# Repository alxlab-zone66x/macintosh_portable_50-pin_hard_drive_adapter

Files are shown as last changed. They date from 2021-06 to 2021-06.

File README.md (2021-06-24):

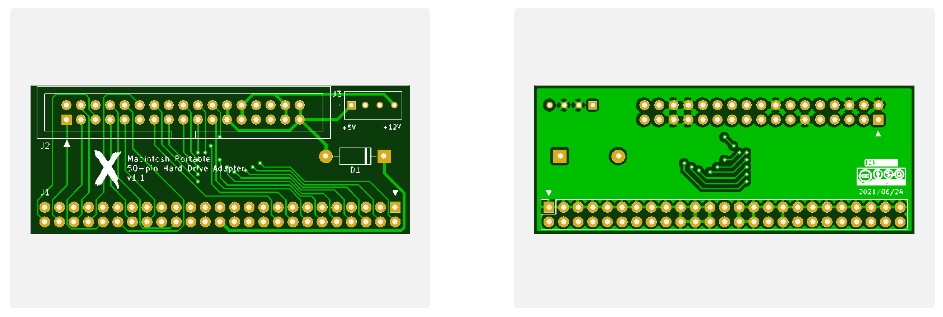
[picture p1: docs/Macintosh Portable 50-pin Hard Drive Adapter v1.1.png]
Macintosh Portable 50-pin Hard Drive Adapter v1.1


# Macintosh Portable 50-pin Hard Drive Adapter v1.1

An adapter to allow you to use any standard 50-pin SCSI device as the Macintosh Portable hard drive. In particular it would work well for connecting directly to the back of a 50-pin SCSI hard drive.

Discord Open Retro SCSI skunkworks

Join us in #skunkworks on [Discord](https://discord.gg/GKcvtgU7P9) to help make retro solutions available to all.

## Bill of Materials

| Quantity | Product Number | Datasheet |
| :--- | --- | --- |
| 1 | BHR-34-VUA | https://app.adam-tech.com/products/download/data_sheet/203218/bhr-xx-vua-data-sheet.pdf |
| 1 | SFH11-PBPC-D17-ST-BK | https://s3.amazonaws.com/catalogspreads-pdf/PAGE123%20.100%20SFH11%20SERIES%20FEMALE%20HDR%20ST%20RA.pdf |
| 1 | 171825-4 | https://media.digikey.com/pdf/Data%20Sheets/Tyco%20Electonics%20AMP%20PDFs/Post%20Headers%20(Board%20Applied).pdf |
| 1 | 1N5818-T | https://www.diodes.com/assets/Datasheets/ds23001.pdf |
| 1 | 34-pin ribbon cable 20cm | https://www.aliexpress.com/item/32985603139.html?spm=a2g0s.9042311.0.0.8a744c4dZvpend |
| 1 | power cable | https://www.aliexpress.com/item/1005002510893961.html?spm=a2g0s.9042311.0.0.38264c4dVYgWFl |

## License



This work is licensed under a <a rel="license" href="http://creativecommons.org/licenses/by-nc-sa/4.0/">Creative Commons Attribution-NonCommercial-ShareAlike 4.0 International License</a>.

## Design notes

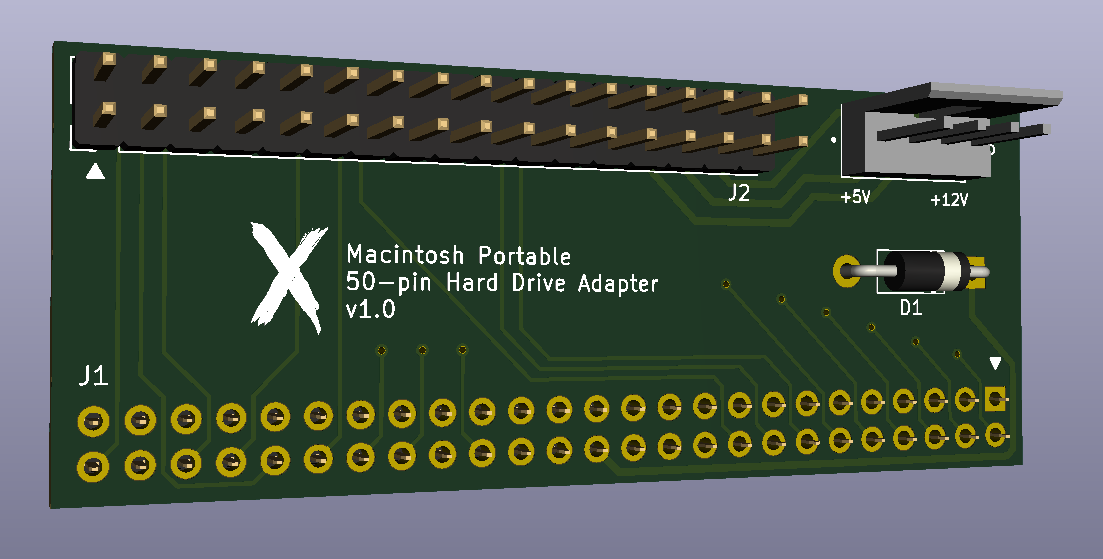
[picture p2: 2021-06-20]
docs/macintosh_portable_50-pin_hard_drive_adapter_v1.0.png

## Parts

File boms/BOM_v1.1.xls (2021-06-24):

Comment | Designator | LCSC Part #（optional） | Part # | Alternate Part # | Quantity | Datasheet
2 x 25-pin 2.54mm polarizing key female header | J1 |  | BHR-34-VUA |  | 1 | https://app.adam-tech.com/products/download/data_sheet/203218/bhr-xx-vua-data-sheet.pdf
2x17-pin 2.54mm shrouded polarizing key male header | J2 |  | SFH11-PBPC-D17-ST-BK | 6834-4500PL | 1 | https://s3.amazonaws.com/catalogspreads-pdf/PAGE123%20.100%20SFH11%20SERIES%20FEMALE%20HDR%20ST%20RA.pdf
4-pin power connector | J3 |  | 171825-4 |  | 1 | https://media.digikey.com/pdf/Data%20Sheets/Tyco%20Electonics%20AMP%20PDFs/Post%20Headers%20(Board%20Applied).pdf
Diode Schottky 30 V 1A Through Hole DO-41 | D1 |  | 1N5818-T |  | 1 | https://www.diodes.com/assets/Datasheets/ds23001.pdf
34-pin ribbon cable |  |  |  |  | 1 | https://www.aliexpress.com/item/32985603139.html?spm=a2g0s.9042311.0.0.8a744c4dZvpend
power cable |  |  |  |  | 1 | https://www.aliexpress.com/item/1005002510893961.html?spm=a2g0s.9042311.0.0.38264c4dVYgWFl

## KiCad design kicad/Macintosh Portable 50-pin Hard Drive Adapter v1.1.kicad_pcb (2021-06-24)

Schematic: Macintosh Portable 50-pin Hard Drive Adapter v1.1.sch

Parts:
D1: DIODE; D_DO-41_SOD81_P10.16mm_Horizontal
J1: SCSI_SE_Internal_Conn_02x25_Odd_Even_MountingPin; PinSocket_2x25_P2.54mm_Vertical
J2: Mac_Portable_SCSI_SE_Conn_02x17_Odd_Even_Mounting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; IDC-Header_2x17_P2.54mm_Vertical
J3: 171825-4; TE_171825-4

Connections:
+5V: D1.1 (K), D1.2 (A), J1.26, J2.23, J2.24, J2.33, J2.34, J3.1
/+12v: J2.25, J2.26, J2.31, J2.32, J3.4
/ACK: J1.38, J2.7
/ATN: J1.32, J2.8
/BSY: J1.36, J2.9
/CD: J1.46, J2.4
/DB0: J1.2, J2.14
/DB1: J1.4, J2.15
/DB2: J1.6, J2.17
/DB3: J1.8, J2.18
/DB4: J1.10, J2.19
/DB5: J1.12, J2.20
/DB6: J1.14, J2.21
/DB7: J1.16, J2.22
/DBP: J1.18, J2.13
/IO: J1.50, J2.5
/MSG: J1.42, J2.3
/REQ: J1.48, J2.1
/RST: J1.40, J2.10
/SEL: J1.44, J2.12
GND: J1.1, J1.3, J1.5, J1.7, J1.9, J1.11, J1.13, J1.15, J1.17, J1.19, J1.20, J1.21, J1.22, J1.23, J1.24, J1.27, J1.28, J1.29, J1.30, J1.31, J1.33, J1.34, J1.35, J1.37, J1.39, J1.41, J1.43, J1.45, J1.47, J1.49, J2.2, J2.6, J2.11, J2.16, J2.27, J2.28, J2.29, J2.30, J3.2, J3.3

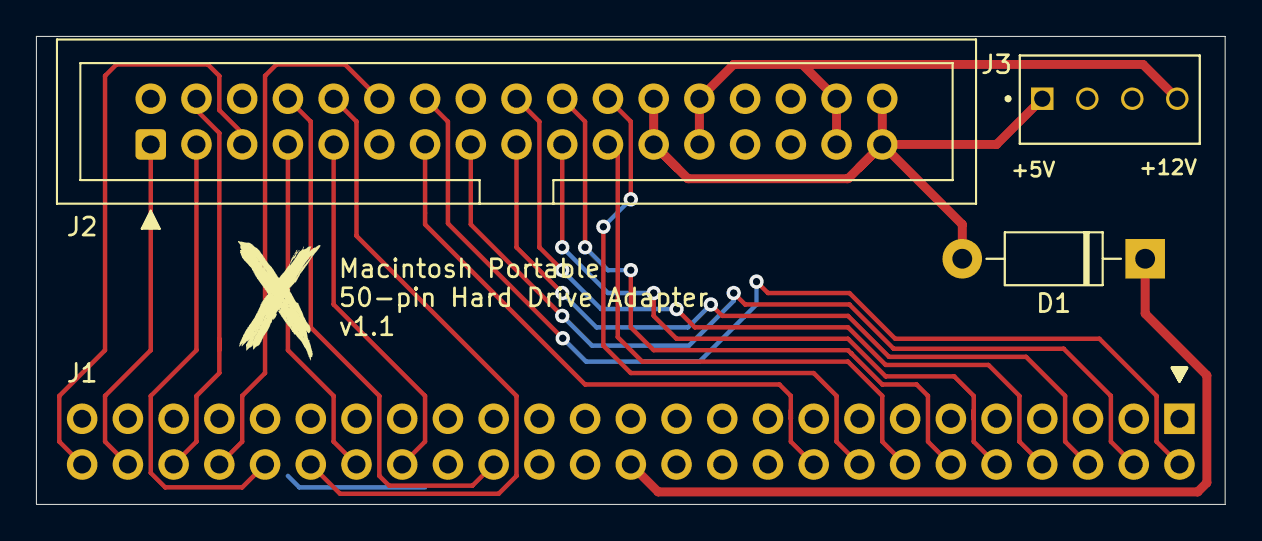
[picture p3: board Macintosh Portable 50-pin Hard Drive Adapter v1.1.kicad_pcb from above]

Board: 2 copper layers, 66.0 x 26.0 mm, 4 parts (1 on the bottom side), 21 nets.

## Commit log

2021-06-20 Macintosh Portable 50-pin Hard Drive Adapter v1.0
    [mac_portable_34pin_to_50pin_scsi.kicad_pcb, mac_portable_34pin_to_50pin_scsi.sch]
2021-06-24 Version 1.1
    [BOM_v1.0.xls, BOM_v1.1.xls, Macintosh Portable 50-pin Hard Drive Adapter v1.1.kicad_pcb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]
